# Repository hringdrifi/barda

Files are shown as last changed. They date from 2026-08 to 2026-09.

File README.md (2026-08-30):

# Blað

Blað is a compact wireless keyboard design project by [hringdrifi](https://github.com/hringdrifi).

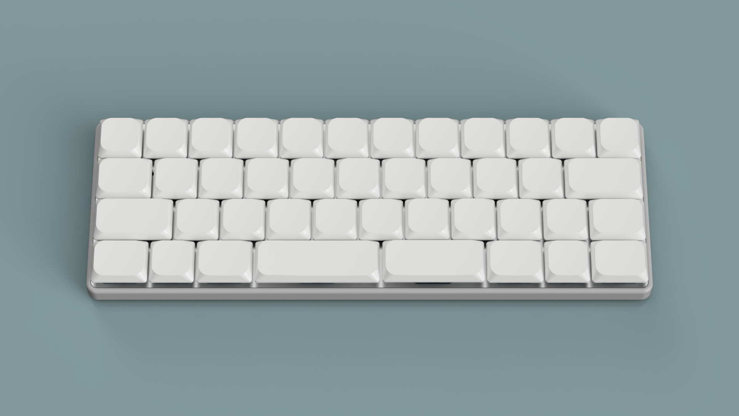
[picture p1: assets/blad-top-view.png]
Blað, top view


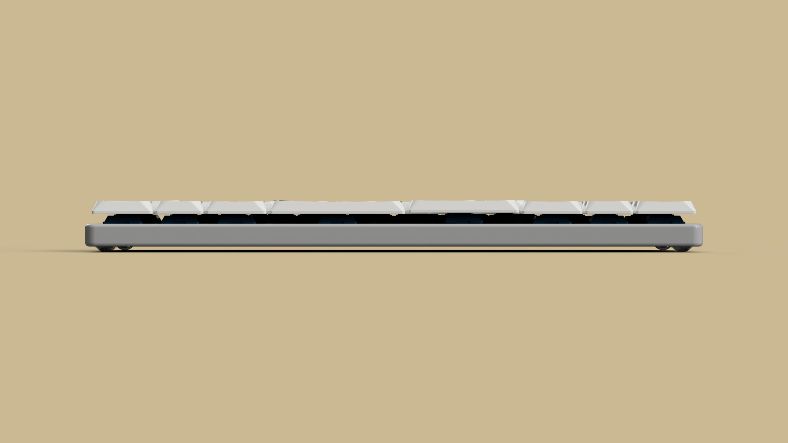
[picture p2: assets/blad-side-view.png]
Blað, side view


The design uses 42 Kailh Choc hot-swap switch positions and an FDK HY0020 Bluetooth Low Energy module based on the Nordic nRF52832.

## Supported components

The design supports the following keyboard components:

- Kailh Choc V2 switches
- Kailh low-profile sockets
- [Chosfox Cross-Core Low-Profile Stabilizers](https://chosfox.com/products/chosfox-cross-core-satellite-switch-for-low-profile-keyboards)

Confirm the exact part variants and mechanical fit before ordering or manufacturing.

## Connectivity and firmware

Blað has no USB connection and supports Bluetooth Low Energy (BLE) only. It is powered by a CR1632 lithium coin cell. A USB-to-serial adapter is required to flash firmware to the keyboard.

## Project status

The PCB and case design files are published in this repository. Validate the design for your intended switches, battery, firmware, manufacturing process, and assembly before building hardware.

## Available files

- [`pcb/`](pcb/) — KiCad source files for the keyboard PCB and plates
  - [`blad.kicad_pcb`](pcb/blad.kicad_pcb) — main keyboard PCB
  - [`blad.kicad_sch`](pcb/blad.kicad_sch) — schematic
  - [`blad_switch_plate.kicad_pcb`](pcb/blad_switch_plate.kicad_pcb) — switch plate PCB
  - [`blad_bottom_plate.kicad_pcb`](pcb/blad_bottom_plate.kicad_pcb) — bottom plate PCB
  - [`smidr.pretty/`](pcb/smidr.pretty/) — custom footprints referenced by the design
  - [`3dmodels/`](pcb/3dmodels/) — STEP models for selected components
- [`case/`](case/) — STEP models for the case assembly
  - [`blad_switch_plate.step`](case/blad_switch_plate.step) — case switch plate
  - [`blad_bumper.step`](case/blad_bumper.step) — bumper layer
  - [`blad_battery_cap.step`](case/blad_battery_cap.step) — battery cap
- [`pcb/README.md`](pcb/README.md) — Smiðr KiCad-export details
- [`case/README.md`](case/README.md) — case-model notes and file roles

## License

The design data in `pcb/` and `case/` is licensed under the [CERN Open Hardware Licence Version 2 - Permissive (CERN-OHL-P-2.0)](LICENSE).

This license permits use, modification, manufacture, and sale of the design data and products made from it. Modified design data does not need to be published, but applicable notices must be retained and modifications must be documented. The design data and any resulting products are provided without warranty.

## Disclaimer

Verify dimensions, clearances, component compatibility, manufacturability, and safety for your own build before making any parts. Use of these files is at your own risk.

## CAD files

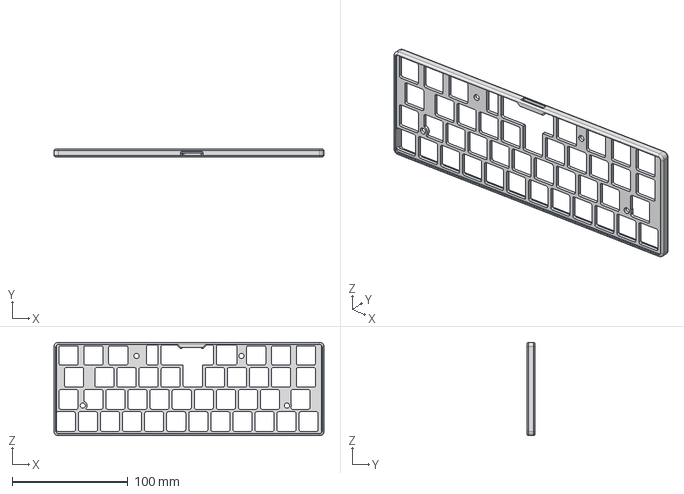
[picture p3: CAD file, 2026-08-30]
case/blad_bumper.step
233.0 x 6.90 x 80.6 mm

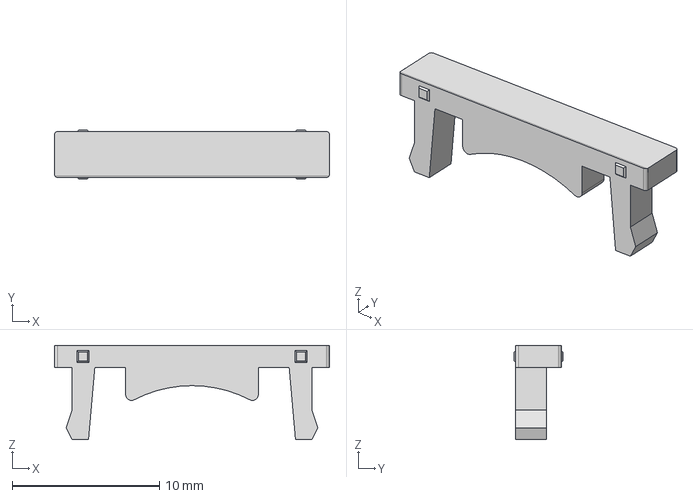
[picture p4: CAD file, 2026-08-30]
case/blad_battery_cap.step
18.6 x 3.30 x 6.38 mm

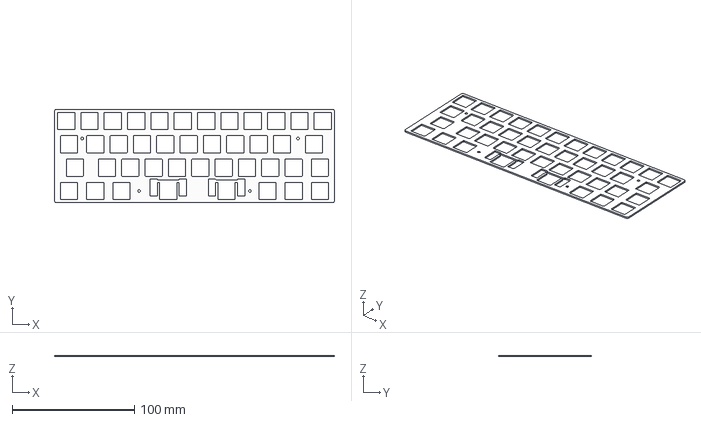
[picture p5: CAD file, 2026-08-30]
case/blad_switch_plate.step
228.6 x 76.2 x 1.20 mm

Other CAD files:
case/barda_switch_plate.step

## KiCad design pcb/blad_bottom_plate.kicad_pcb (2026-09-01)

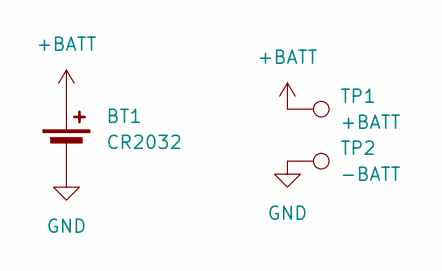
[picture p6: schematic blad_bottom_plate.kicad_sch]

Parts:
BT1: CR2032; BAT-SMD_MY-1632-03
TP1: +BATT; TestPoint_Keystone_5019_Miniature
TP2: -BATT; TestPoint_Keystone_5019_Miniature

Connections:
+BATT: BT1.1 (+), TP1.1 (1_1)
GND: BT1.2 (-), TP2.1 (1_1)

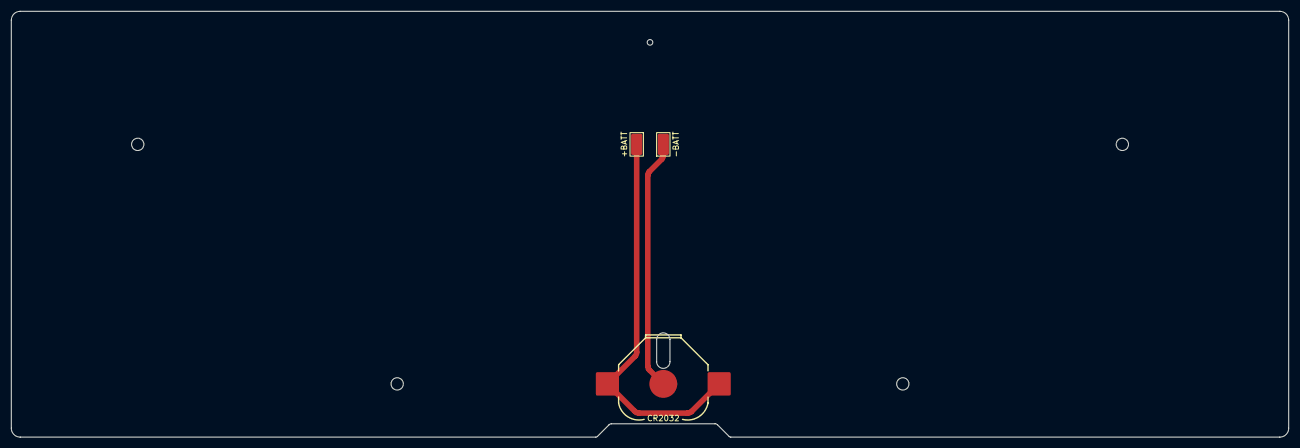
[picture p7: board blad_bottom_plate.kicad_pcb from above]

Board: 2 copper layers, 228.6 x 76.2 mm, 3 parts (0 on the bottom side), 2 nets.

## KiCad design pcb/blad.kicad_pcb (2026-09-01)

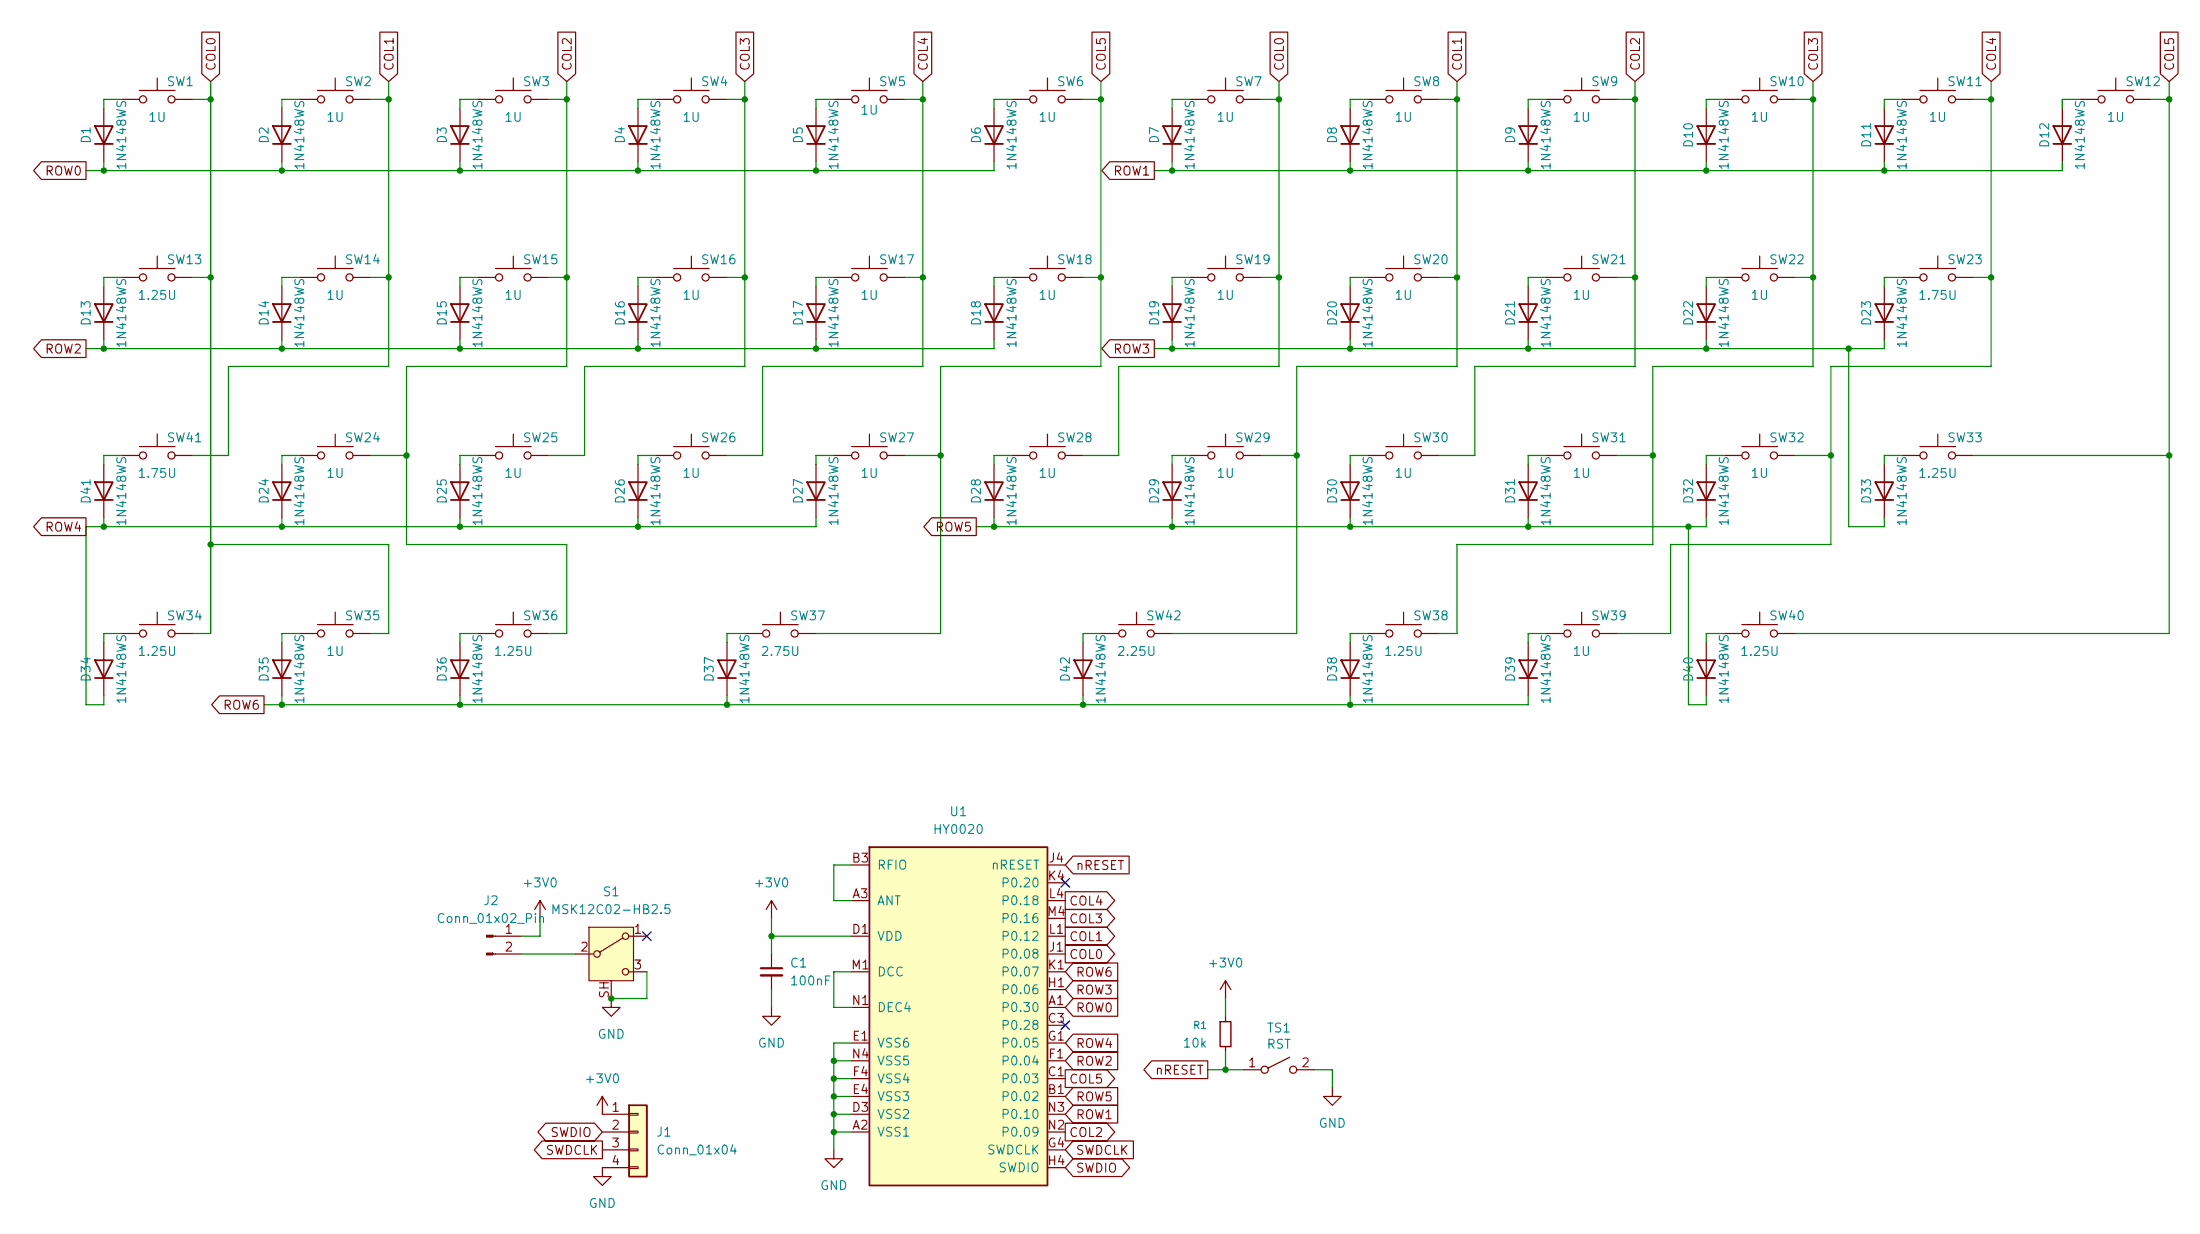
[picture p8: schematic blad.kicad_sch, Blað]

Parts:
C1: 100nF; C_0402_1005Metric
D1, D2, D3, D4, D5, D6, D7, D8, D9, D10, D11, D12, D13, D14, D15, D16, D17, D18, D19, D20, D21, D22, D23, D24, D25, D26, D27, D28, D29, D30, D31, D32, D33, D34, D35, D36, D37, D38, D39, D40, D41, D42: 1N4148WS; D_SOD-123
J1: Conn_01x04; PinHeader_1x04_P2.54mm_Vertical
J2: Conn_01x02_Pin; PinHeader_1x02_P2.54mm_Vertical
R1: 10k; R_0402_1005Metric
S1: MSK12C02-HB2.5; SW_SPDT_Shouhan_MSK12C02; JLCPCB Part # C47020937
SW1, SW2, SW3, SW4, SW5, SW6, SW7, SW8, SW9, SW10, SW11, SW12, SW14, SW15, SW16, SW17, SW18, SW19, SW20, SW21, SW22, SW24, SW25, SW26, SW27, SW28, SW29, SW30, SW31, SW32, SW35, SW39: 1U; SW_Smidr_Choc_Hotswap
SW13, SW33, SW34, SW36, SW38, SW40: 1.25U; SW_Smidr_Choc_Hotswap
SW23, SW41: 1.75U; SW_Smidr_Choc_Hotswap
SW37: 2.75U; SW_Smidr_Choc_Hotswap
SW42: 2.25U; SW_Smidr_Choc_Hotswap
TS1: RST; SW_Push_SPST_NO_Alps_SKRK
U1: HY0020; RF_Module_FDK_HY0020

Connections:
+3V0: C1.1, J1.1, J2.1, R1.1, U1.D1 (VDD)
COL0: SW1.2, SW7.2, SW13.2, SW19.2, SW28.2, SW34.2, SW35.2, U1.J1 (P0.08)
COL1: SW2.2, SW8.2, SW14.2, SW20.2, SW29.2, SW41.2, SW42.2, U1.L1 (P0.12)
COL2: SW3.2, SW9.2, SW15.2, SW21.2, SW24.2, SW30.2, SW36.2, U1.N2 (P0.09)
COL3: SW4.2, SW10.2, SW16.2, SW22.2, SW25.2, SW31.2, SW38.2, U1.M4 (P0.16)
COL4: SW5.2, SW11.2, SW17.2, SW23.2, SW26.2, SW32.2, SW39.2, U1.L4 (P0.18)
COL5: SW6.2, SW12.2, SW18.2, SW27.2, SW33.2, SW37.2, SW40.2, U1.C1 (P0.03)
GND: C1.2, J1.4, S1.3 (C), S1.SH, TS1.2 (B), U1.A2 (VSS1), U1.D3 (VSS2), U1.E1 (VSS6), U1.E4 (VSS3), U1.F4 (VSS4), U1.N4 (VSS5)
unnamed: D1.2 (A), SW1.1
unnamed: D2.2 (A), SW2.1
unnamed: D3.2 (A), SW3.1
unnamed: D4.2 (A), SW4.1
unnamed: D5.2 (A), SW5.1
unnamed: D6.2 (A), SW6.1
unnamed: D7.2 (A), SW7.1
unnamed: D8.2 (A), SW8.1
unnamed: D9.2 (A), SW9.1
unnamed: D10.2 (A), SW10.1
unnamed: D11.2 (A), SW11.1
unnamed: D12.2 (A), SW12.1
unnamed: D13.2 (A), SW13.1
unnamed: D14.2 (A), SW14.1
unnamed: D15.2 (A), SW15.1
unnamed: D16.2 (A), SW16.1
unnamed: D17.2 (A), SW17.1
unnamed: D18.2 (A), SW18.1
unnamed: D19.2 (A), SW19.1
unnamed: D20.2 (A), SW20.1
unnamed: D21.2 (A), SW21.1
unnamed: D22.2 (A), SW22.1
unnamed: D23.2 (A), SW23.1
unnamed: D24.2 (A), SW24.1
unnamed: D25.2 (A), SW25.1
unnamed: D26.2 (A), SW26.1
unnamed: D27.2 (A), SW27.1
unnamed: D28.2 (A), SW28.1
unnamed: D29.2 (A), SW29.1
unnamed: D30.2 (A), SW30.1
unnamed: D31.2 (A), SW31.1
unnamed: D32.2 (A), SW32.1
unnamed: D33.2 (A), SW33.1
unnamed: D34.2 (A), SW34.1
unnamed: D35.2 (A), SW35.1
unnamed: D36.2 (A), SW36.1
unnamed: D37.2 (A), SW37.1
unnamed: D38.2 (A), SW38.1
unnamed: D39.2 (A), SW39.1
unnamed: D40.2 (A), SW40.1
unnamed: D41.2 (A), SW41.1
unnamed: D42.2 (A), SW42.1
unnamed: J2.2, S1.2 (B)
unnamed: U1.A3 (ANT), U1.B3 (RFIO)
unnamed: U1.M1 (DCC), U1.N1 (DEC4)
ROW0: D1.1 (K), D2.1 (K), D3.1 (K), D4.1 (K), D5.1 (K), D6.1 (K), U1.A1 (P0.30)
ROW1: D7.1 (K), D8.1 (K), D9.1 (K), D10.1 (K), D11.1 (K), D12.1 (K), U1.N3 (P0.10)
ROW2: D13.1 (K), D14.1 (K), D15.1 (K), D16.1 (K), D17.1 (K), D18.1 (K), U1.F1 (P0.04)
ROW3: D19.1 (K), D20.1 (K), D21.1 (K), D22.1 (K), D23.1 (K), D33.1 (K), U1.H1 (P0.06)
ROW4: D24.1 (K), D25.1 (K), D26.1 (K), D27.1 (K), D34.1 (K), D41.1 (K), U1.G1 (P0.05)
ROW5: D28.1 (K), D29.1 (K), D30.1 (K), D31.1 (K), D32.1 (K), D40.1 (K), U1.B1 (P0.02)
ROW6: D35.1 (K), D36.1 (K), D37.1 (K), D38.1 (K), D39.1 (K), D42.1 (K), U1.K1 (P0.07)
SWDCLK: J1.3, U1.G4 (SWDCLK)
SWDIO: J1.2, U1.H4 (SWDIO)
nRESET: R1.2, TS1.1 (A), U1.J4 (nRESET)

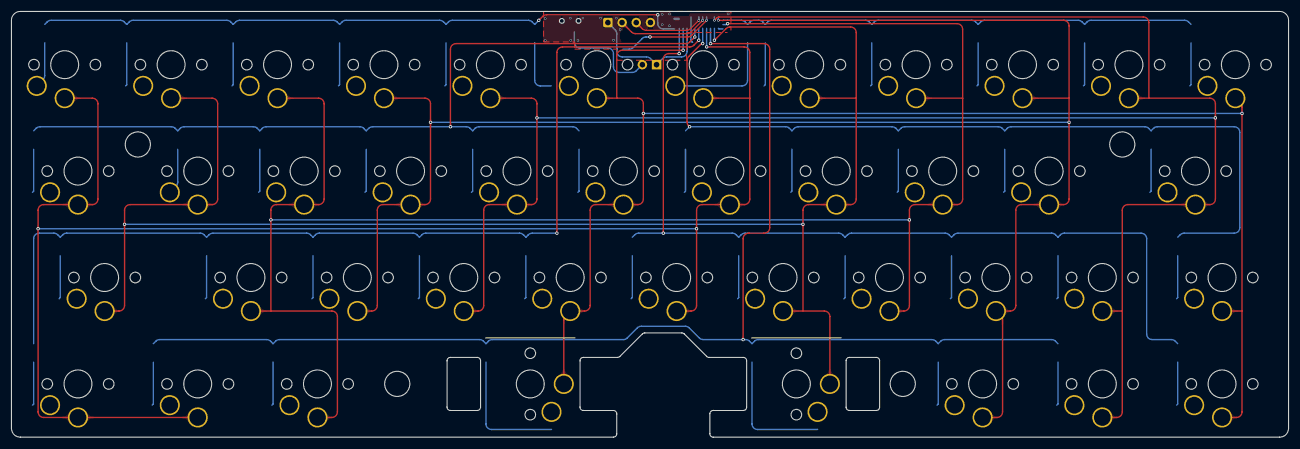
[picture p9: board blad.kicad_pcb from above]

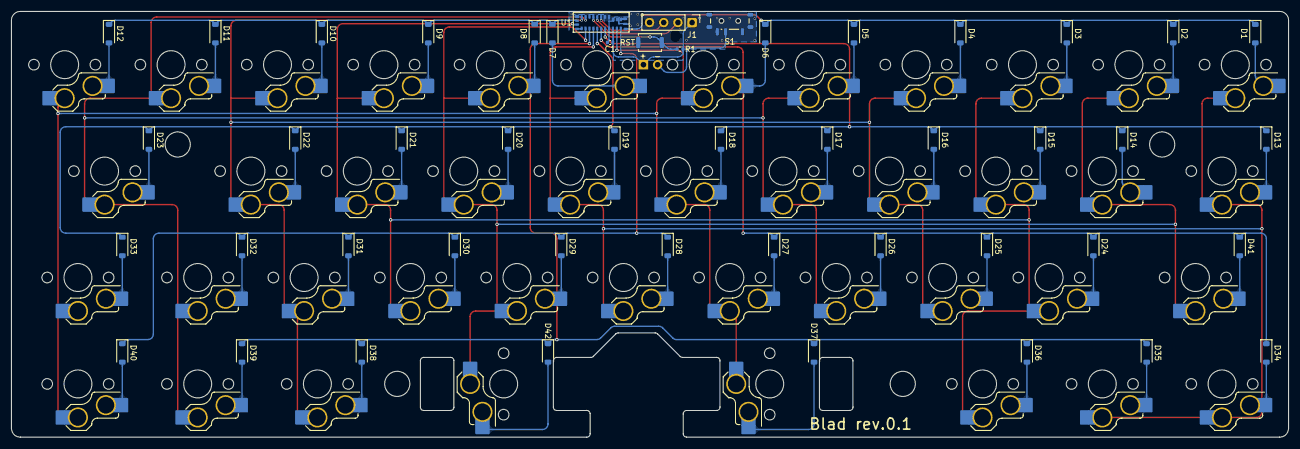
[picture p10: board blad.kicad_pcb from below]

Board: 2 copper layers, 228.6 x 76.2 mm, 91 parts (91 on the bottom side), 63 nets.

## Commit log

2026-08-24 Remove unused footprints
2026-08-24 Document CR1632 battery
2026-08-24 Ignore top-level PCB STEP exports
2026-08-24 Add case 3D models and update PCB assets
    [Low Profile Keycap 1.25U.step, Low Profile Keycap 1.75U.step, Low Profile Keycap 1U.step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]
2026-08-24 Document case STEP models
2026-08-24 Update keyboard PCB layout
    [barda.kicad_pcb]
2026-08-24 Update via drill size to 0.3 mm
    [barda.kicad_pcb]
2026-08-24 Remove missing VRML model reference
    [barda.kicad_pcb]
2026-08-25 Update Barda PCB and case design
    [barda.kicad_pcb, barda.kicad_sch, barda_switch_plate.step]
2026-08-28 Update Barda case and PCB design
    [barda.kicad_pcb, barda.kicad_sch, barda_bottom_plate.kicad_pcb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]
2026-08-29 Update PCB and case for M2 4mm standoffs
    [barda.kicad_pcb, barda.kicad_sch, barda_bottom_plate.kicad_pcb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]
2026-08-29 Update bumper case and PCB
    [barda.kicad_pcb, barda_bumper.step]
2026-08-29 Update Barda case and PCB designs
    [barda.kicad_pcb, barda_bottom_plate.kicad_pcb, barda_bumper.step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]
2026-09-01 Update PCB design
    [blad.kicad_pcb, blad_bottom_plate.kicad_pcb]
